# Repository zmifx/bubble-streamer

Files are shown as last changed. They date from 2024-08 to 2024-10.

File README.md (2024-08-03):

# How to fix S*daStream?
Somehow it happened that this bubbler stopped working-only the LEDs were flashing (no, a new power adapter did not help).
Attempts to repair the original control board did not work, it is simply too complicated for me. So I simply made a new PCB, radically simplified, built on an Arduino Micro and many of the original parts. Here are some data files. NO WARRANTY, FOR STUDY PURPOSES ONLY!
* The original one
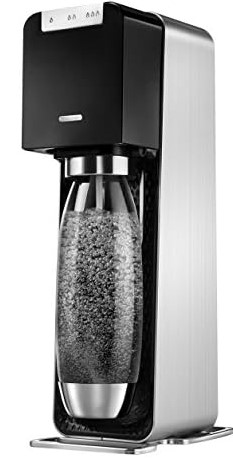
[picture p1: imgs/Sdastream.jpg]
OMG original device


* New PCB
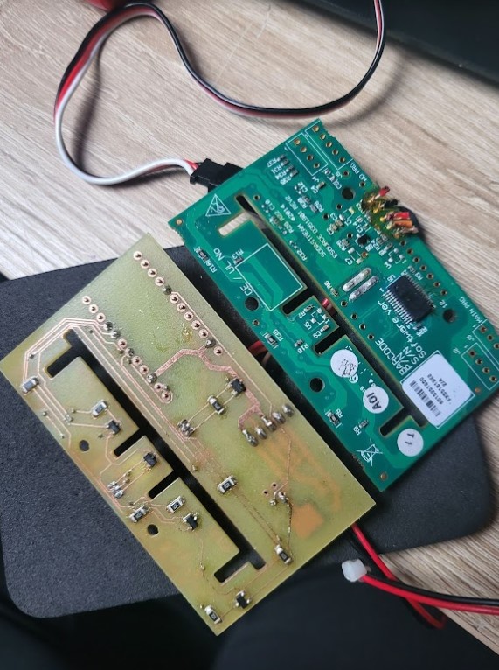
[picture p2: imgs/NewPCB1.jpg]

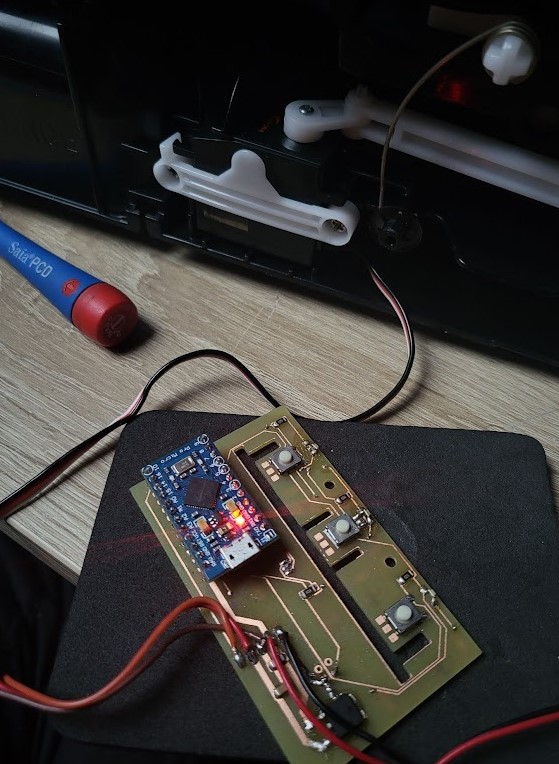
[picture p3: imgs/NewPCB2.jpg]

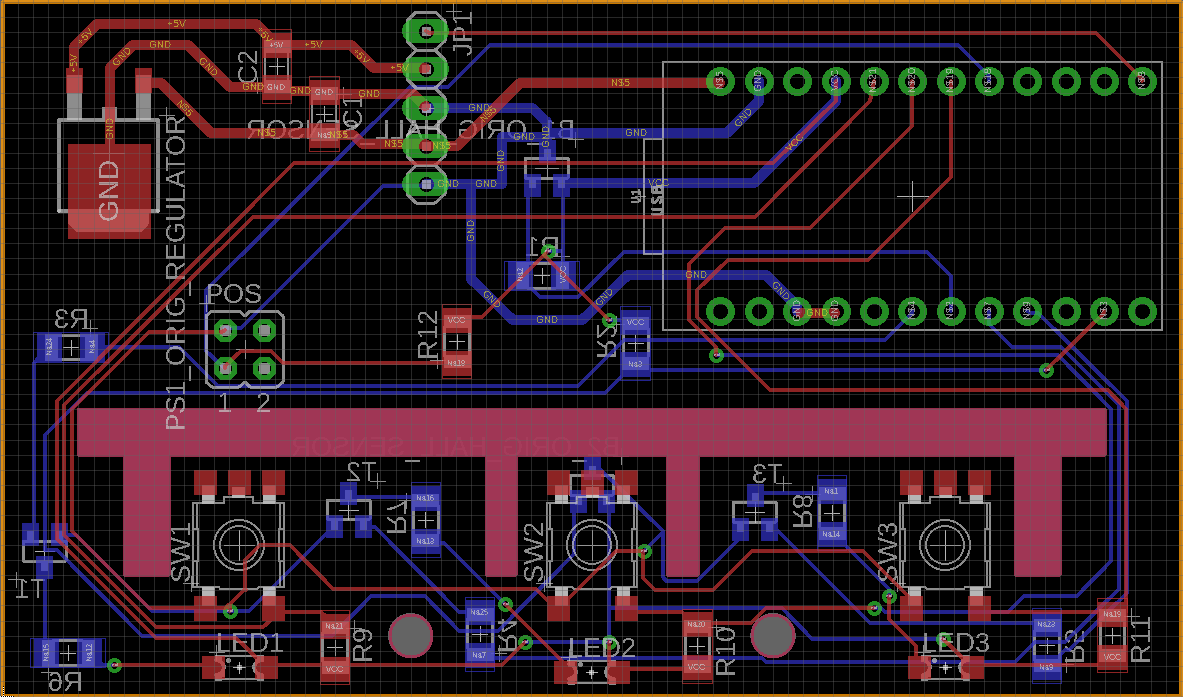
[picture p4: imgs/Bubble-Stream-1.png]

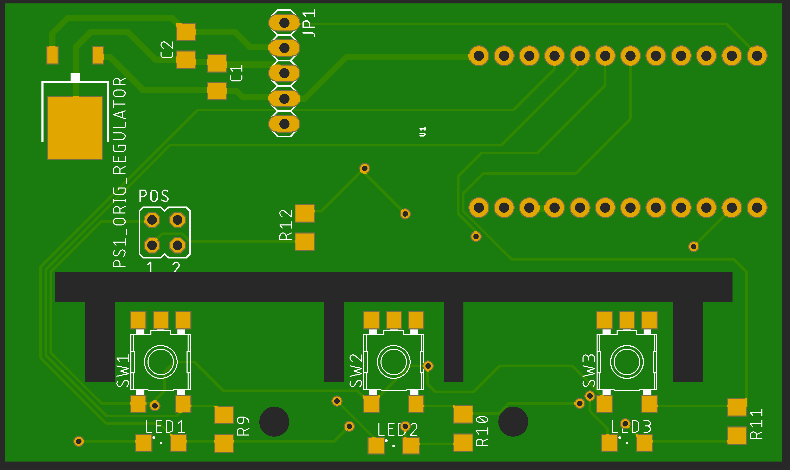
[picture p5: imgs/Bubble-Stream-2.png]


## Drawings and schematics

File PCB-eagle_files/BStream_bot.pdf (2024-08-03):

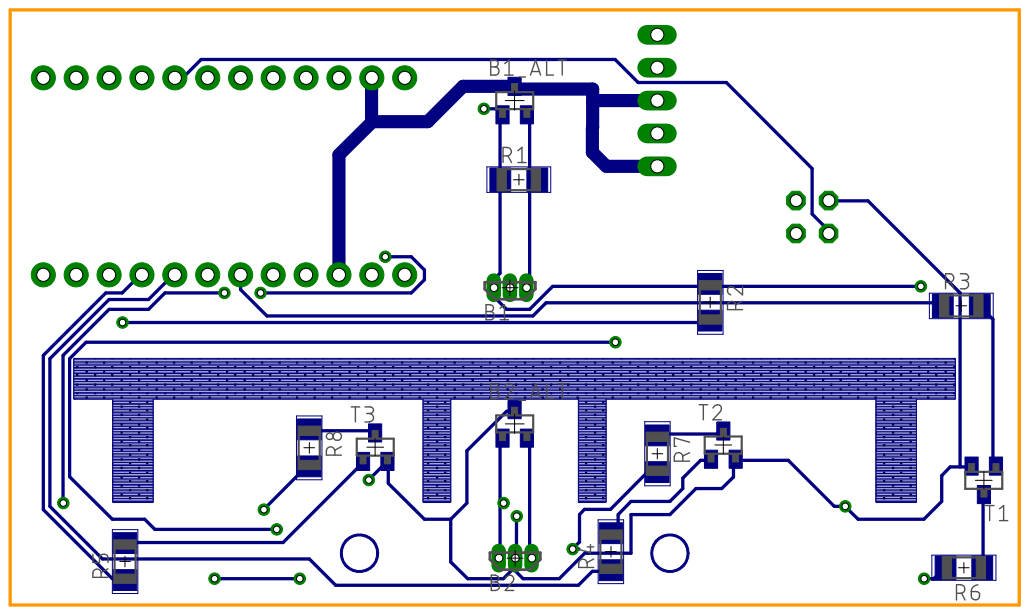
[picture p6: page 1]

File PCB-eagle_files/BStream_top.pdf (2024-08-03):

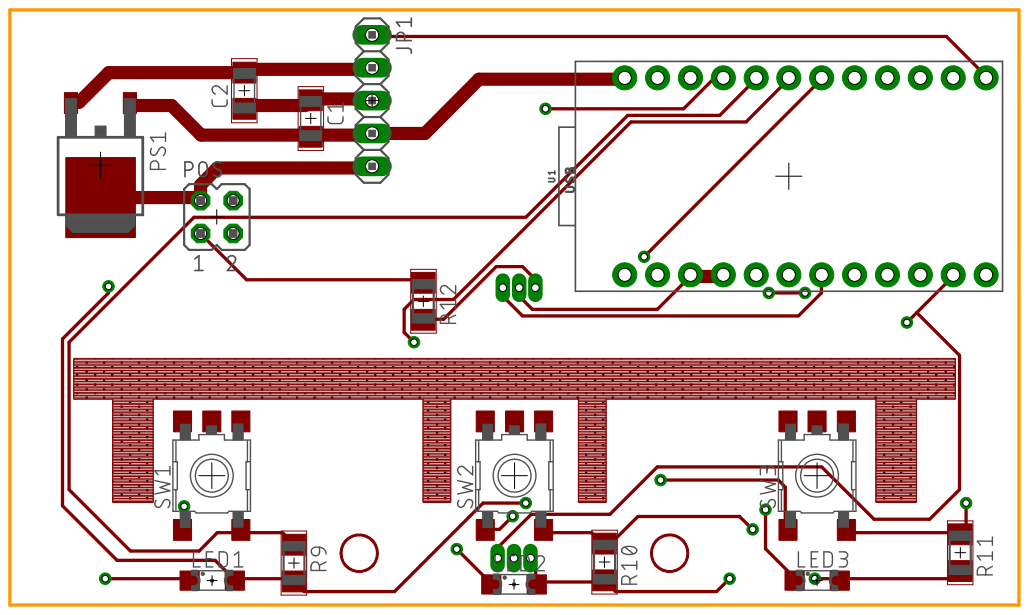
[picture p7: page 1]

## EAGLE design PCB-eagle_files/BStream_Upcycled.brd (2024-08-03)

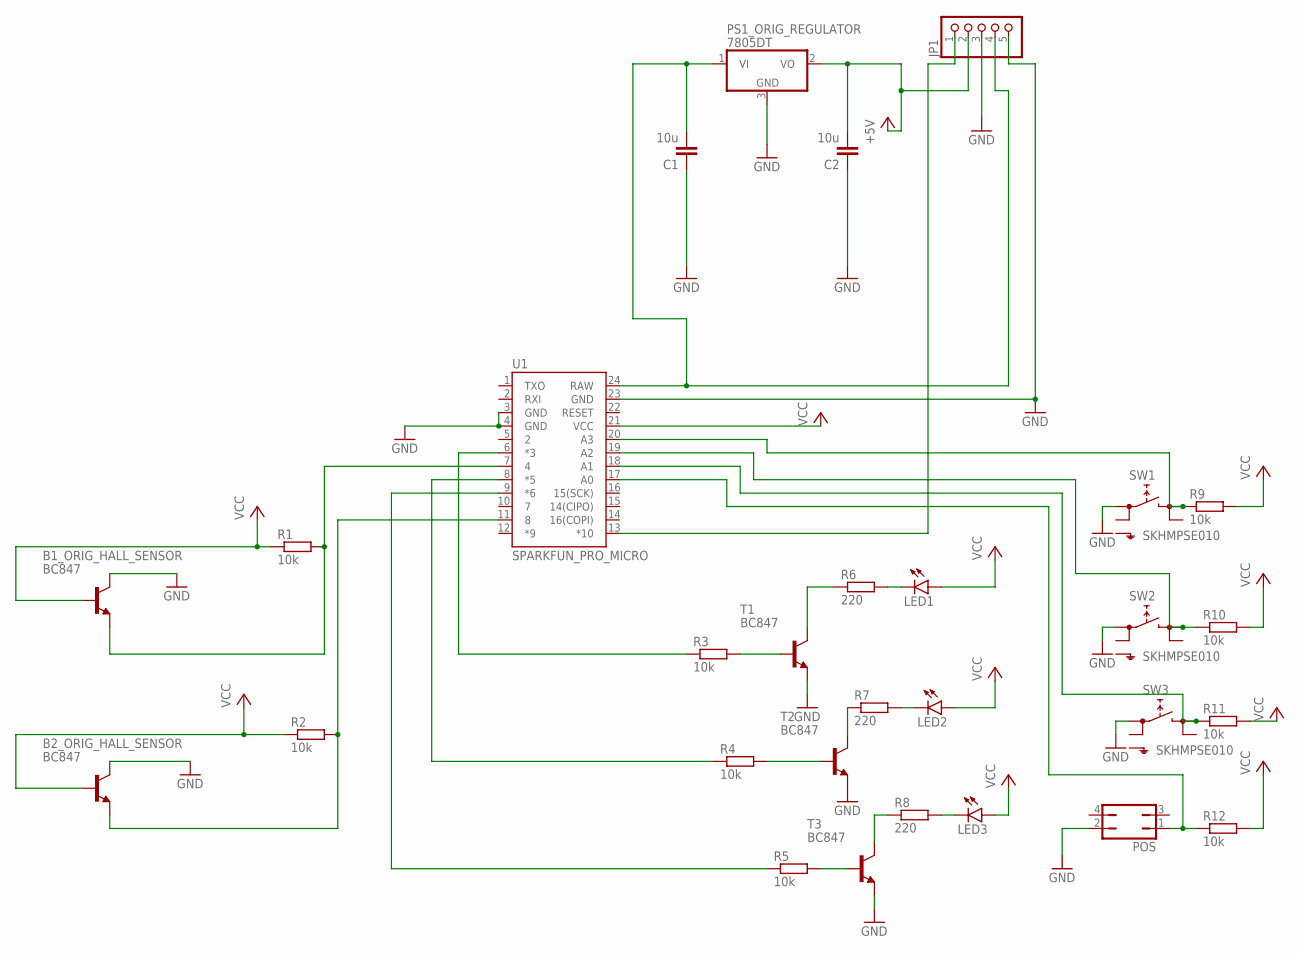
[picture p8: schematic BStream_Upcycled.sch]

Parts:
B1_ORIG_HALL_SENSOR, B2_ORIG_HALL_SENSOR: BC847; SOT23
C1, C2: 10u; C1206
JP1: PINHD-1X5; 1X05
LED1, LED2, LED3: LEDSML1206; SML1206
POS: JP2Q
PS1_ORIG_REGULATOR: 7805DT; TO252
R1, R2, R3, R4, R5, R9, R10, R11, R12: 10k; R1206
R6, R7, R8: 220; R1206
SW1, SW2, SW3: SKHMPSE010; SKHMPXE010
T1, T2, T3: BC847; SOT23
U1: SPARKFUN_PRO_MICRO

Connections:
+5V: C2.2, JP1.2, PS1_ORIG_REGULATOR.2 (VO)
GND: B1_ORIG_HALL_SENSOR.3 (C), B2_ORIG_HALL_SENSOR.3 (C), C1.1, C2.1, JP1.3, JP1.5, POS.2, PS1_ORIG_REGULATOR.3 (GND), SW1.1 (1.1), SW2.1 (1.1), SW3.1 (1.1), T1.2 (E), T2.2 (E), T3.2 (E), U1.3 (GND), U1.4 (GND), U1.23 (GND)
unnamed: R8.1, T3.3 (C)
unnamed: B1_ORIG_HALL_SENSOR.2 (E), R1.2, U1.7 (4)
unnamed: B2_ORIG_HALL_SENSOR.2 (E), R2.2, U1.11 (8)
unnamed: R3.1, U1.6 (*3)
unnamed: C1.2, JP1.4, PS1_ORIG_REGULATOR.1 (VI), U1.24 (RAW)
unnamed: R4.1, U1.8 (*5)
unnamed: JP1.1, U1.13 (*10)
unnamed: R5.1, U1.9 (*6)
unnamed: LED1.C, R6.2
unnamed: LED2.C, R7.2
unnamed: LED3.C, R8.2
unnamed: R6.1, T1.3 (C)
unnamed: R7.1, T2.3 (C)
unnamed: POS.1, R12.1, U1.17 (A0)
unnamed: R11.1, SW3.3 (2.1), U1.18 (A1)
unnamed: R10.1, SW2.3 (2.1), U1.19 (A2)
unnamed: R9.1, SW1.3 (2.1), U1.20 (A3)
unnamed: R5.2, T3.1 (B)
unnamed: R3.2, T1.1 (B)
unnamed: R4.2, T2.1 (B)
VCC: B1_ORIG_HALL_SENSOR.1 (B), B2_ORIG_HALL_SENSOR.1 (B), LED1.A, LED2.A, LED3.A, R1.1, R2.1, R9.2, R10.2, R11.2, R12.2, U1.21 (VCC)

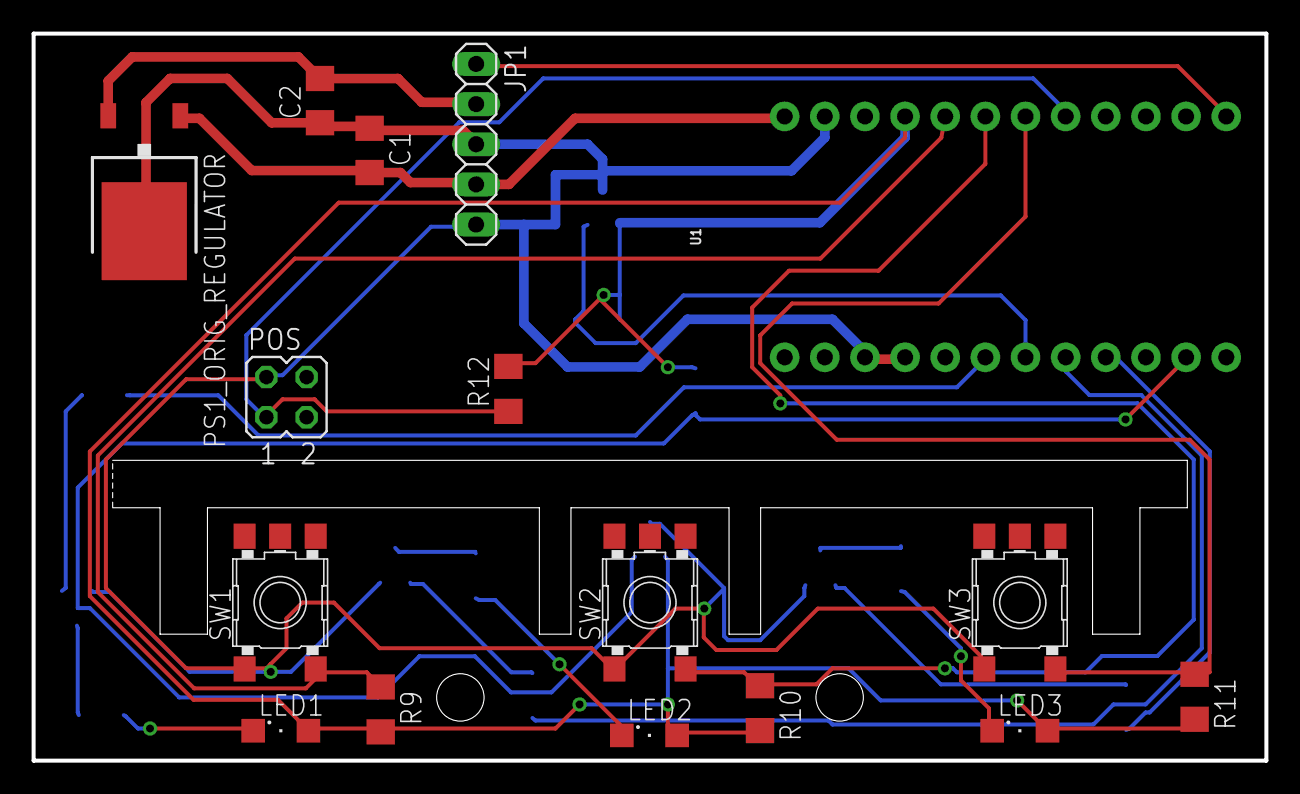
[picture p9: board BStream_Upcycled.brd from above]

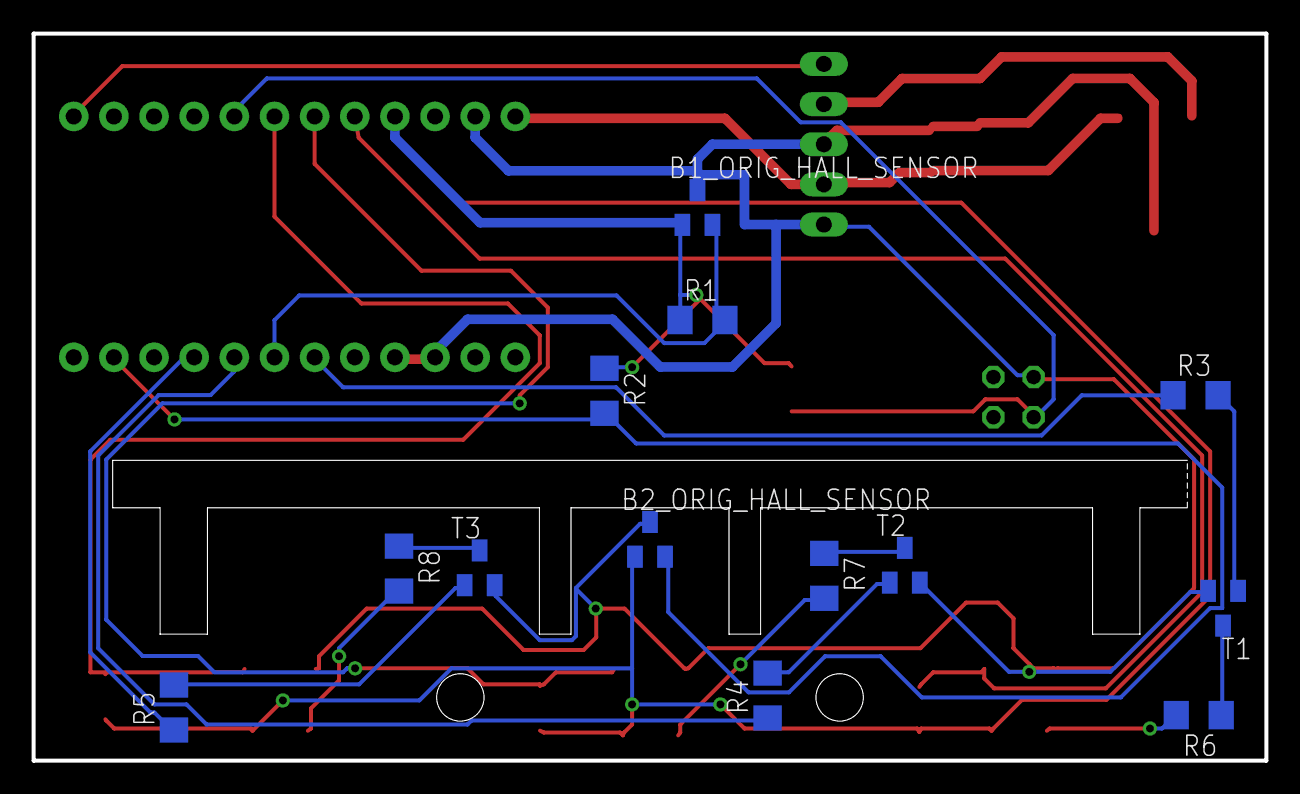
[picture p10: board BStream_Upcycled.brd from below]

Board: 2 copper layers, 78.0 x 46.0 mm, 29 parts (13 on the bottom side), 23 nets.

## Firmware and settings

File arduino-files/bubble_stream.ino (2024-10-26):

// LEONARDO !!!!!!!!


#include <ServoEasing.hpp>

ServoEasing myServo;  // Create an instance of the Servo class to control the servo motor

int buttonAPin = A3;  // Pin for button A
int buttonBPin = A2;  // Pin for button B
int buttonCPin = A1;  // Pin for button C

int ledAPin = 3;  // Pin for LED button A
int ledBPin = 5;  // Pin for LED button B
int ledCPin = 6;  // Pin for LED button C

int magnetServoReachPin = A8;
int magnetHomePin = A6;
int verticalPositionPin = A0;

bool isBlinkingA = false;
bool isBlinkingB = false;
bool isBlinkingC = false;
extern bool movementDone = false;

unsigned long previousMillisA = 0;
unsigned long previousMillisB = 0;
unsigned long previousMillisC = 0;

unsigned long time_now = 0;

const long interval = 200;  // LED blink interval (in milliseconds)

void ServoTargetPositionReachedHandler(ServoEasing *aServoEasingInstance);

void setup() {

  pinMode(buttonAPin, INPUT);
  pinMode(buttonBPin, INPUT);
  pinMode(buttonCPin, INPUT);

  pinMode(magnetServoReachPin, INPUT);
  pinMode(magnetHomePin, INPUT);
  pinMode(verticalPositionPin, INPUT);

  pinMode(ledAPin, OUTPUT);
  pinMode(ledBPin, OUTPUT);
  pinMode(ledCPin, OUTPUT);
  
  while (digitalRead(magnetHomePin) == HIGH){
      delay(100);      
  }
  
  myServo.attach(10, 30);  //Servo motor assignment to pin 10, set position to 30 degrees

  myServo.setSpeed(60);  // This speed is taken if no further speed argument is given.
  myServo.setTargetPositionReachedHandler(ServoTargetPositionReachedHandler);
}

void loop() {
  if (digitalRead(magnetHomePin) == HIGH) {
    startBlinkingAll();
  } else {
    handleButton(3, buttonCPin, ledCPin, isBlinkingC, previousMillisC, movementDone);    
    handleButton(2, buttonBPin, ledBPin, isBlinkingB, previousMillisB, movementDone);
    handleButton(1, buttonAPin, ledAPin, isBlinkingA, previousMillisA, movementDone);
  }

}

void handleButton(int id, int buttonPin, int ledPin, bool &isBlinking, unsigned long &previousMillis, bool &movementDone) {
  if (digitalRead(buttonPin) == LOW) {
    if (!isBlinking) {
      startBlinking(ledPin, isBlinking, previousMillis);
      rotateServo(id, movementDone);  // Turn the servo motor by 1x
    }
  } else {
    stopBlinking(ledPin, isBlinking);
  }
}

void rotateServo(int rotations, bool &movementDone) {
  for (int i = 0; i < rotations; ++i) {
    movementDone = false;
    myServo.startEaseTo(115);                 // Rotate to position 115 degrees
    HandleBreakableDelay(1500, movementDone);  // Pause
    movementDone = false;
    myServo.startEaseTo(30);                  // Rotate to position 30 degrees
    HandleBreakableDelay(400, movementDone);  // Pause
  }
}

void startBlinking(int ledPin, bool &isBlinking, unsigned long &previousMillis) {
  isBlinking = true;
  previousMillis = millis();
  analogWrite(ledPin, 16);  // LED on
}

void stopBlinking(int ledPin, bool &isBlinking) {
  isBlinking = false;
  analogWrite(ledPin, 0);  // LED off
}


void HandleBreakableDelay(unsigned long msecondsToDelay, bool &movementDone) {
  while (movementDone == false) {
    if (digitalRead(magnetHomePin) == HIGH) {
      // Serial.println("magnetServoReachPin = LOW");
      myServo.stop();
      ErrorEndLoop();
      break;
    } else {
      //  Serial.println("magnetServoReachPin = HIGH");
    }
    delay(10);
  }
  time_now = millis();
  //Serial.println("millis ");
  while (millis() < (time_now + msecondsToDelay)) {
    //wait approx. [period] ms    
    delay(10);
  }
}

void ServoTargetPositionReachedHandler(ServoEasing *aServoEasingInstance) {
  movementDone = true;
}
void ErrorEndLoop() {
  myServo.startEaseTo(30); 
  while (true) {

    startBlinkingAll();

  }
}

void startBlinkingAll() {
  analogWrite(ledAPin, 16);
  analogWrite(ledBPin, 16);
  analogWrite(ledCPin, 16);
  delay(400);
  analogWrite(ledAPin, 0);
  analogWrite(ledBPin, 0);
  analogWrite(ledCPin, 0);
  delay(400);
}

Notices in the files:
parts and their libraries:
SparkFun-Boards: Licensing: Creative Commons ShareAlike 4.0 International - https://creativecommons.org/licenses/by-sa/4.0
